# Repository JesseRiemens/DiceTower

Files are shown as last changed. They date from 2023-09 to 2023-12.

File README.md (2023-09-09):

# DiceTower - A 3D-Printed Electronic Dice Tower

View this project on [CADLAB.io](https://cadlab.io/project/27312).

## System Architecture Diagram

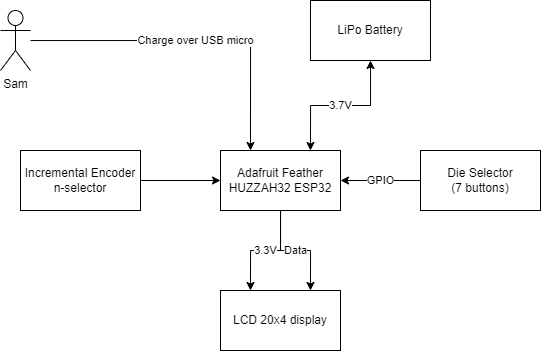
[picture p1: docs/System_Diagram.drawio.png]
System Architecture Diagram


## Bill of Materials

| Item | Quantity | Price (Estimated) | Link |
| --- | --- | --- | --- |
| ESP32 Feather Huzzah32 | 1 | $20.22 | [DigiKey-ESP32] |
| LCD 20x4 | 1 | $20.26 | [DigiKey-LCD] |
| PCB | 1 | $5.00 | [PCBWay]; [JLCPCB] |
| 3D-Printed Parts | 1 | $10.00 |
| Incremental Encoder | 1 | $1.00 | [TinyTronics-Encoder] |
| Encoder Knob | 1 | $1.00 | [TinyTronics-Encoder-Knob] |
| Dice (d4, d6, d8, d10, d12, d20, d100) | 1 | $10.00 |
| Switches | 7 | $9.99 |
| Dice keycaps printed | 7 | $1.00 |
| Boost Converter | 1 | $2.00 | [TinyTronics-Boost-Converter] |
| Battery | 1 | $5.00 | [TinyTronics-Battery] |

[DigiKey-ESP32]: https://www.digikey.nl/en/products/detail/adafruit-industries-llc/3619/8119806
[DigiKey-LCD]: https://www.digikey.nl/en/products/detail/newhaven-display-intl/NHD-0420AZ-FSW-GBW-33V3/2773596
[PCBWay]: https://www.pcbway.com
[JLCPCB]: https://jlcpcb.com
[TinyTronics-Encoder]: https://www.tinytronics.nl/shop/nl/schakelaars/manuele-schakelaars/rotary-encoders/rotary-encoder-module
[TinyTronics-Encoder-Knob]: https://www.tinytronics.nl/shop/nl/componenten/knoppen,-doppen-en-kapjes/potmeter-knop-zwart
[TinyTronics-Boost-Converter]: https://www.tinytronics.nl/shop/en/power/voltage-converters/boost-(step-up)-converters/mini-dc-dc-3.3v-step-up-boost-converter-400ma
[TinyTronics-Battery]: https://www.tinytronics.nl/shop/en/power/batteries/li-po/li-po-battery-3.7v-1250mah-jst-ph-lp554050

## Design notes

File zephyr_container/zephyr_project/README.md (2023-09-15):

# Zephyr Example Application

## Jesses Notes

To init:

(Execute from the root of the repository)

```shell
cd zephyr_container/zephyr_project && west init -l . && west update 
source ../zephyr/zephyr-env.sh && python3 -m venv .venv && source .venv/bin/activate && pip3 install -r ../zephyr/scripts/requirements.txt 
```

To build:

```shell
source ../zephyr/zephyr-env.sh && source .venv/bin/activate && west build -b esp32_devkitc_wroom app
```

To flash:

```shell
source ../zephyr/zephyr-env.sh && source .venv/bin/activate && west flash
```

This repository contains a Zephyr example application. The main purpose of this
repository is to serve as a reference on how to structure Zephyr-based
applications. Some of the features demonstrated in this example are:

- Basic [Zephyr application][app_dev] skeleton
- [Zephyr workspace applications][workspace_app]
- [Zephyr modules][modules]
- [West T2 topology][west_t2]
- [Custom boards][board_porting]
- Custom [devicetree bindings][bindings]
- Out-of-tree [drivers][drivers]
- Out-of-tree libraries
- Example CI configuration (using Github Actions)
- Custom [west extension][west_ext]

This repository is versioned together with the [Zephyr main tree][zephyr]. This
means that every time that Zephyr is tagged, this repository is tagged as well
with the same version number, and the [manifest](west.yml) entry for `zephyr`
will point to the corresponding Zephyr tag. For example, the `example-application`
v2.6.0 will point to Zephyr v2.6.0. Note that the `main` branch always
points to the development branch of Zephyr, also `main`.

[app_dev]: https://docs.zephyrproject.org/latest/develop/application/index.html
[workspace_app]: https://docs.zephyrproject.org/latest/develop/application/index.html#zephyr-workspace-app
[modules]: https://docs.zephyrproject.org/latest/develop/modules.html
[west_t2]: https://docs.zephyrproject.org/latest/develop/west/workspaces.html#west-t2
[board_porting]: https://docs.zephyrproject.org/latest/guides/porting/board_porting.html
[bindings]: https://docs.zephyrproject.org/latest/guides/dts/bindings.html
[drivers]: https://docs.zephyrproject.org/latest/reference/drivers/index.html
[zephyr]: https://github.com/zephyrproject-rtos/zephyr
[west_ext]: https://docs.zephyrproject.org/latest/develop/west/extensions.html

## Getting Started

Before getting started, make sure you have a proper Zephyr development
environment. Follow the official
[Zephyr Getting Started Guide](https://docs.zephyrproject.org/latest/getting_started/index.html).

### Initialization

The first step is to initialize the workspace folder (``my-workspace``) where
the ``example-application`` and all Zephyr modules will be cloned. Run the following
command:

```shell
# initialize my-workspace for the example-application (main branch)
west init -m https://github.com/zephyrproject-rtos/example-application --mr main my-workspace
# update Zephyr modules
cd my-workspace
west update
```

### Building and running

To build the application, run the following command:

```shell
west build -b $BOARD app
```

where `$BOARD` is the target board.

You can use the `custom_plank` board found in this
repository. Note that Zephyr sample boards may be used if an
appropriate overlay is provided (see `app/boards`).

A sample debug configuration is also provided. To apply it, run the following
command:

```shell
west build -b $BOARD app -- -DOVERLAY_CONFIG=debug.conf
```

Once you have built the application, run the following command to flash it:

```shell
west flash
```

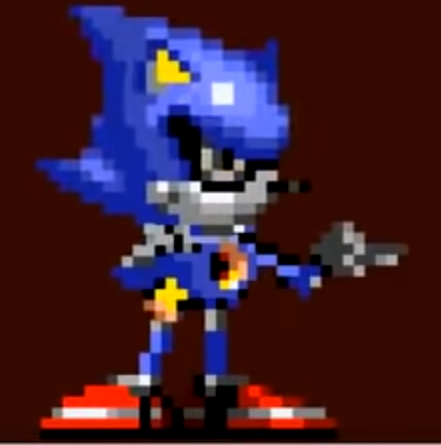
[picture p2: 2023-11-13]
chronic the hedgebloc.png

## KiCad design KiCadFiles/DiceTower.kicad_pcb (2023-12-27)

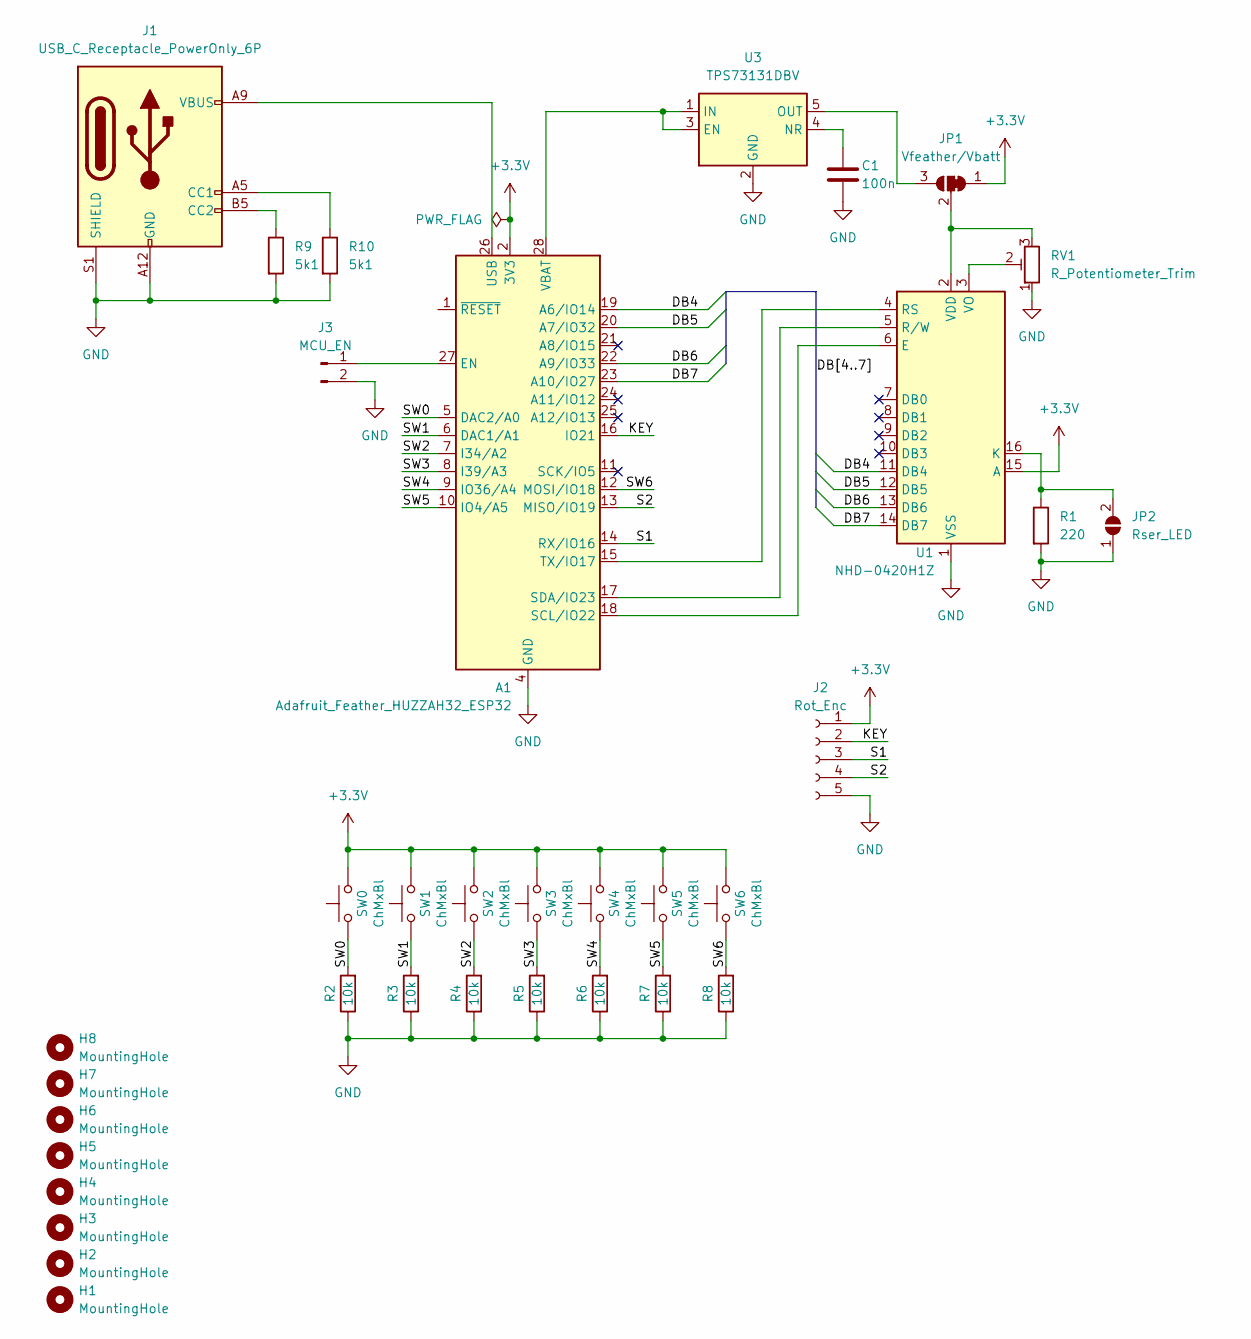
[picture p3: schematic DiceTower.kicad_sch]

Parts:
A1: Adafruit_Feather_HUZZAH32_ESP32; Adafruit_Feather
C1: 100n; C_0603_1608Metric
H1, H2, H3, H4, H5, H6, H7, H8: MountingHole; MountingHole_3.2mm_M3_ISO14580
J1: USB_C_Receptacle_PowerOnly_6P; USB_C_Receptacle_GCT_USB4125-xx-x-0190_6P_TopMnt_Horizontal
J2: Rot_Enc; PinSocket_1x05_P2.54mm_Vertical
J3: MCU_EN; PinHeader_1x02_P2.54mm_Vertical
JP1: Vfeather/Vbatt; SolderJumper-3_P1.3mm_Bridged12_RoundedPad1.0x1.5mm_NumberL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
JP2: Rser_LED; SolderJumper-2_P1.3mm_Open_RoundedPad1.0x1.5mm
R1: 220; R_0603_1608Metric_Pad0.98x0.95mm_HandSolder
R2, R3, R4, R5, R6, R7, R8: 10k; R_0603_1608Metric_Pad0.98x0.95mm_HandSolder
R9, R10: 5k1; R_0603_1608Metric_Pad0.98x0.95mm_HandSolder
RV1: R_Potentiometer_Trim; Potentiometer_Bourns_3266W_Vertical
SW0, SW1, SW2, SW3, SW4, SW5, SW6: ChMxBl; SW_Cherry_MX_1.00u_PCB
U1: NHD-0420H1Z; PinHeader_1x16_P2.54mm_Vertical
U3: TPS73131DBV; SOT-23-5

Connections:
+3.3V: A1.2 (3V3), J2.1, JP1.1 (A), SW0.2, SW1.2, SW2.2, SW3.2, SW4.2, SW5.2, SW6.2, U1.15 (A)
/DB4: A1.19 (A6/IO14), U1.11 (DB4)
/DB5: A1.20 (A7/IO32), U1.12 (DB5)
/DB6: A1.22 (A9/IO33), U1.13 (DB6)
/DB7: A1.23 (A10/IO27), U1.14 (DB7)
/KEY: A1.16 (IO21), J2.2
/S1: A1.14 (RX/IO16), J2.3
/S2: A1.13 (MISO/IO19), J2.4
/SW0: A1.5 (DAC2/A0), R2.2, SW0.1
/SW1: A1.6 (DAC1/A1), R3.2, SW1.1
/SW2: A1.7 (I34/A2), R4.2, SW2.1
/SW3: A1.8 (I39/A3), R5.2, SW3.1
/SW4: A1.9 (IO36/A4), R6.2, SW4.1
/SW5: A1.10 (IO4/A5), R7.2, SW5.1
/SW6: A1.12 (MOSI/IO18), R8.2, SW6.1
GND: A1.4 (GND), C1.2, J1.A12 (GND), J1.B12 (GND), J1.S1 (SHIELD), J2.5, J3.2, JP2.1 (A), R1.2, R2.1, R3.1, R4.1, R5.1, R6.1, R7.1, R8.1, R9.2, R10.2, RV1.1, U1.1 (VSS), U3.2 (GND)
unnamed: A1.27 (EN), J3.1
unnamed: A1.18 (SCL/IO22), U1.6 (E)
unnamed: A1.17 (SDA/IO23), U1.5 (R/W)
unnamed: A1.15 (TX/IO17), U1.4 (RS)
unnamed: A1.26 (USB), J1.A9 (VBUS), J1.B9 (VBUS)
unnamed: A1.28 (VBAT), U3.1 (IN), U3.3 (EN)
unnamed: J1.A5 (CC1), R10.1
unnamed: J1.B5 (CC2), R9.1
unnamed: JP1.3 (B), U3.5 (OUT)
unnamed: JP1.2 (C), RV1.3, U1.2 (VDD)
unnamed: JP2.2 (B), R1.1, U1.16 (K)
unnamed: RV1.2, U1.3 (VO)
unnamed: C1.1, U3.4 (NR)

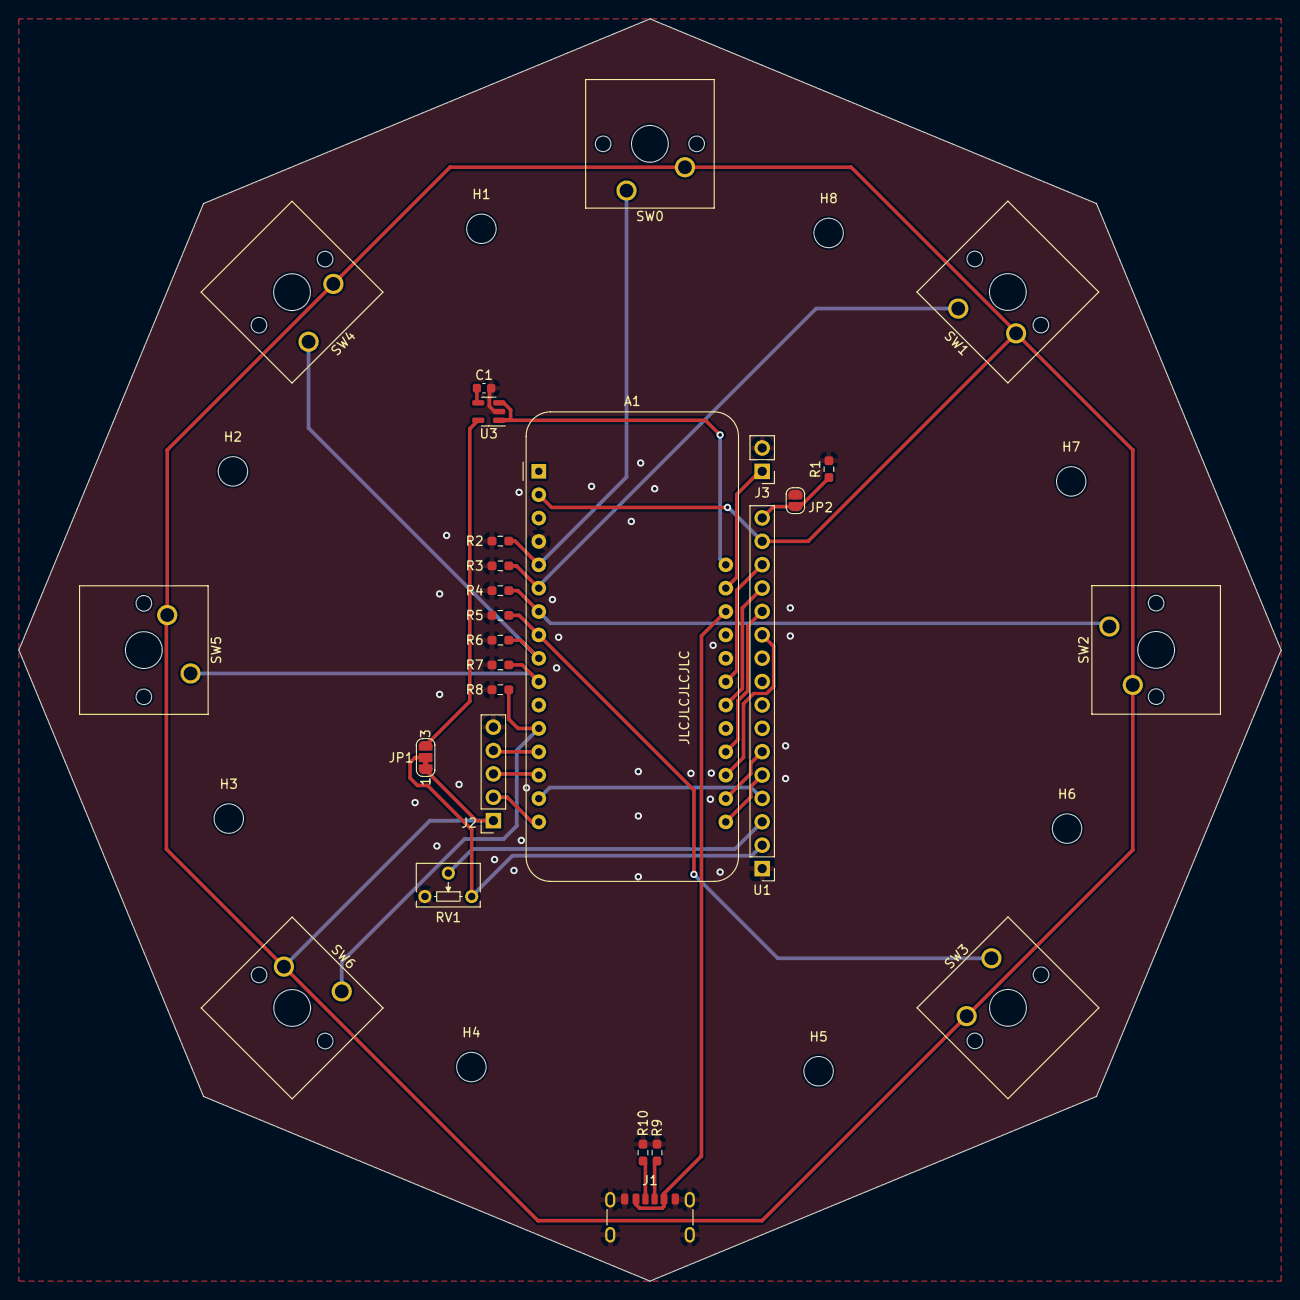
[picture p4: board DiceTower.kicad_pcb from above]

Board: 2 copper layers, 137.2 x 137.2 mm, 35 parts (0 on the bottom side), 29 nets.

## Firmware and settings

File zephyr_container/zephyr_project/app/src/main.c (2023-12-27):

/*
 * Copyright (c) 2023 Jamie McCrae
 *
 * SPDX-License-Identifier: Apache-2.0
 */

#include <string.h>
#include <zephyr/device.h>
#include <zephyr/drivers/auxdisplay.h>
#include <zephyr/kernel.h>
#include <zephyr/logging/log.h>

LOG_MODULE_REGISTER(auxdisplay_sample, LOG_LEVEL_DBG);

int main(void) {
  int rc;
  const struct device *const dev = DEVICE_DT_GET(DT_NODELABEL(auxdisplay_0));
  uint8_t data[6] = "Hello";

  if (!device_is_ready(dev)) {
    LOG_ERR("Auxdisplay device is not ready.");
    return 0;
  }

  rc = auxdisplay_cursor_set_enabled(dev, false);

  if (rc != 0) {
    LOG_ERR("Failed to enable cursor: %d", rc);
  }

  // snprintk(data, sizeof(data), "Hello world from %s", CONFIG_BOARD);
  while (true) {

    rc = auxdisplay_write(dev, data, strlen(data));

    if (rc != 0) {
      LOG_ERR("Failed to write data: %d", rc);
    }
    LOG_INF("Sent data: %s", data);

    // rc =
    //     auxdisplay_cursor_position_set(dev, AUXDISPLAY_POSITION_ABSOLUTE, 0,
    //     0);
    // if (rc != 0) {
    //   LOG_ERR("Failed to set cursor position: %d", rc);
    // }

    k_sleep(K_MSEC(1000));
  }

  LOG_INF("Sample application has completed.");
  return 0;
}

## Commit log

2023-09-09 Schematic draft
    [DiceTower.kicad_pcb, DiceTower.kicad_sch]
2023-09-09 Add system diagram
    [DiceTower.kicad_pcb, DiceTower.kicad_sch]
2023-09-09 Add BOM
2023-09-09 Add BOM, updated schematics
    [DiceTower.kicad_sch]
2023-09-09 Update BOM
    [DiceTower.kicad_sch]
2023-09-10 Change display to 3.3V
2023-09-10 Add PCB
    [DiceTower.kicad_pcb, DiceTower.kicad_sch]
2023-09-15 Add three threads
2023-11-07 Moved board to key circle
    [DiceTower.kicad_pcb]
2023-11-08 Added usb-c connector
    [DiceTower.kicad_pcb, DiceTower.kicad_sch]
2023-11-08 Finish PCB
    [DiceTower.kicad_pcb]
2023-11-09 Try to add gerbers pipeline
    [DiceTower.kicad_pcb, DiceTower.kicad_sch, PCB layout v3.dxf]
2023-11-10 Change resistor location
    [DiceTower.kicad_pcb]
2023-11-11 Add mounting holes
    [DiceTower.kicad_pcb, DiceTower.kicad_sch]
2023-11-13 Edit outline edgecuts
    [DiceTower.kicad_pcb]
2023-11-13 Collect all the chaos nachos!
    [DiceTower.kicad_pcb]
2023-12-03 Fix board platform
2023-12-04 Add sample driver for this display
2023-12-27 Remove unused esp32 overlay
    [DiceTower.kicad_pcb]
